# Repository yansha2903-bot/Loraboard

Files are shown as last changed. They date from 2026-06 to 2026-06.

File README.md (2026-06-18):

# LoraBoard
A custom ESP32-S3 LoRa development board designed for long-range wireless communication projects.

## Overview
LoraBoard is a custom PCB designed around the ESP32-S3 microcontroller and the SX1262 LoRa transceiver. The board is intended for low-power, long-range communication applications such as mesh networking, remote monitoring, IoT devices, and sensor networks.

The project was designed using KiCad and includes a complete schematic, PCB layout, and manufacturing files.

## Features
- ESP32-S3 microcontroller
- SX1262 LoRa transceiver
- USB connectivity for programming and power
- Compact PCB design
- Long-range wireless communication
- Suitable for Meshtastic and IoT applications
- Hardware
- Main Components
- ESP32-S3
- SX1262 LoRa Radio
- USB Interface
- Antenna Connector
- Repository Structure

## Images



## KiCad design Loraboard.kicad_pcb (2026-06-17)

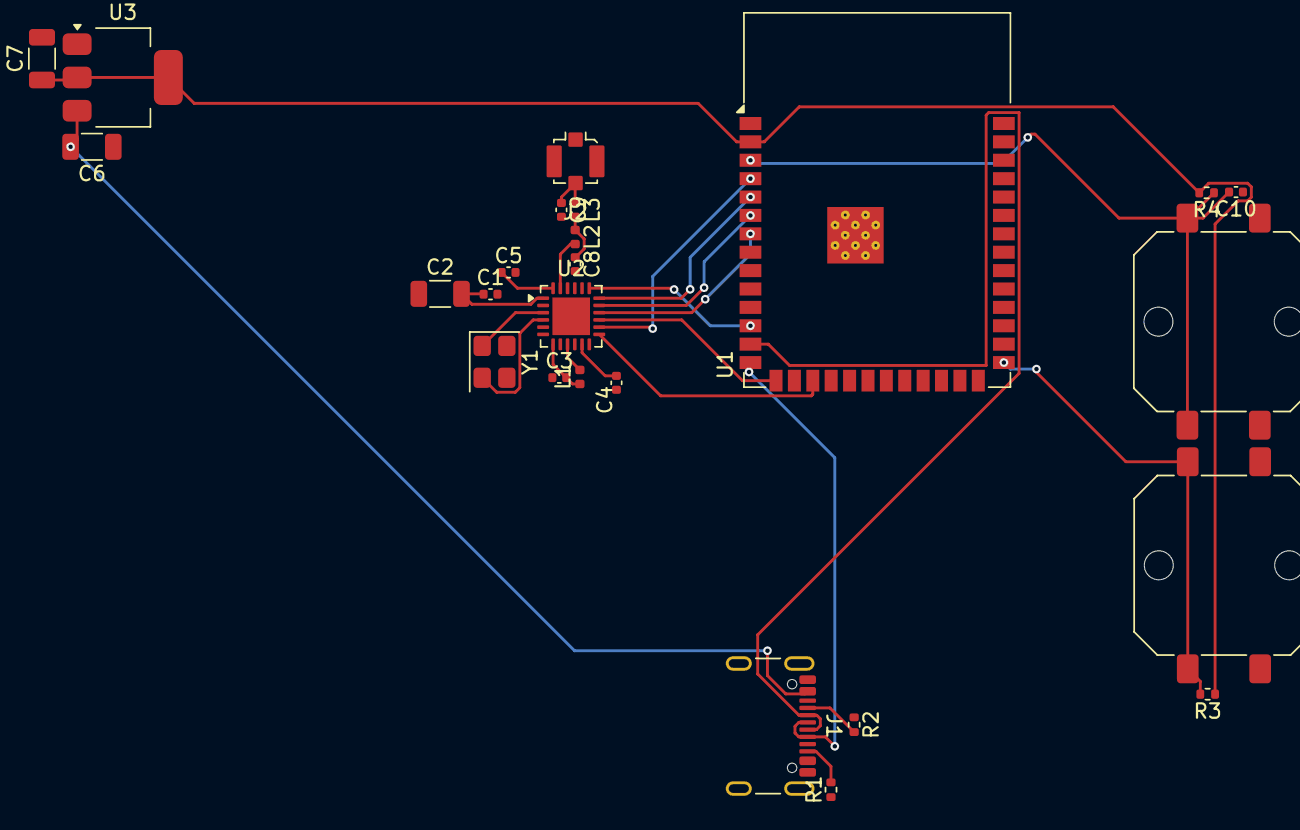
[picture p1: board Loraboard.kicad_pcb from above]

Board: 2 copper layers, 25 parts (0 on the bottom side), 26 nets.

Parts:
C1, C3, C4, C5, C10: 100nF; C_0402_1005Metric
C2, C6, C7: 10µF; C_1206_3216Metric
C8: 2.7pF; C_0402_1005Metric
C9: 3.3pF; C_0402_1005Metric
J1: USB_C_Receptacle_USB2.0_14P; USB_C_Receptacle_GCT_USB4105-xx-A_16P_TopMnt_Horizontal
J2: Conn_Coaxial; U.FL_Molex_MCRF_73412-0110_Vertical
L1: 15µH; L_0402_1005Metric
L2: 3.9nH; L_0402_1005Metric
L3: 12nH; L_0402_1005Metric
R1, R2: 5.1k; R_0402_1005Metric
R3, R4: 10kΩ; R_0402_1005Metric
SW1, SW2: SW_Push; SW_Push_1P1T_NO_CK_PTS125Sx85PSMTR
U1: ESP32-S3-WROOM-1
U2: SX1262IMLTRT; QFN-24-1EP_4x4mm_P0.5mm_EP2.6x2.6mm
U3: AMS1117-3.3; SOT-223-3_TabPin2
Y1: 32 MHz; Crystal_SMD_3225-4Pin_3.2x2.5mm

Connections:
+3V3: C7.1, R3.1, R4.2, U1.2 (3V3), U3.2 (VO)
+5V: C6.2, J1.A4 (VBUS), J1.A9 (VBUS), J1.B4 (VBUS), J1.B9 (VBUS), U3.3 (VI)
/BUSY: U1.4 (IO4), U2.14 (BUSY)
/DIO1: U1.17 (IO9), U2.13 (DIO1)
/MISO: U1.7 (IO7), U2.16 (MISO)
/MOSI: U1.6 (IO6), U2.17 (MOSI)
/NSS: U1.12 (IO8), U2.19 (NSS)
/RESET: U1.15 (IO3), U2.15 (~RESET)
/SCK: U1.5 (IO5), U2.18 (SCK)
/USB_D+: J1.A6 (D+), J1.B6 (D+), U1.14 (USB_D+)
/USB_D-: J1.A7 (D-), J1.B7 (D-), U1.13 (USB_D-)
GND: C1.2, C2.1, C3.1, C4.1, C5.2, C6.1, C7.2, C8.2, C9.2, C10.1, J1.A1 (GND), J1.A12 (GND), J1.B1 (GND), J1.B12 (GND), J2.2 (Ext), R1.1, R2.1, SW1.1, SW2.1, U1.1 (GND), U1.40 (GND), U1.41 (GND), U2.2 (GND), U2.5 (GND), U2.8 (GND), U2.20 (GND), U2.25 (GND), U3.1 (GND)
unnamed: C8.1, L2.1, L3.2
unnamed: J1.A5 (CC1), R2.2
unnamed: J1.B5 (CC2), R1.2
unnamed: C9.1, J2.1 (In), L3.1
unnamed: C10.2, R4.1, SW2.2, U1.3 (EN)
unnamed: R3.2, SW1.2, U1.27 (IO0)
unnamed: L1.2, U2.9 (DCC_SW)
unnamed: L2.2, U2.23 (RFO)
unnamed: C4.2, U2.11 (VBAT_IO)
unnamed: C1.1, C2.2, U2.1 (VDD_IN)
unnamed: C3.2, L1.1, U2.7 (VREG)
unnamed: C5.1, U2.24 (VR_PA)
unnamed: U2.3 (XTA), Y1.1
unnamed: U2.4 (XTB), Y1.2
